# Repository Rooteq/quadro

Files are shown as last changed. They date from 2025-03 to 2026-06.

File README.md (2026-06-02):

# Quadro
Quadro is the name of my ros2 quadruped project.

## Overview
I'm developing 12 DoF quadruped robot as a part of my master theses as well as my hobby.
The project consists of:
- 3D printed physical physical - fully designed by me. The motors are Steadywin gim6010-8 connected to Raspberry Pi 5 with the use of CAN bus. In the future Nvidia Jetson Orin Nano will be added as a secondary computer for visual SLAM.
- Simulated robot in Isaac Lab.

Right now, only the naive position controller works - robot is able to walk, but only in crawl (one leg up at one time). Model-based predictive controller is in the works.
Controllers, hardware interface and internal communication are based on ROS2 Jazzy libraries. It requires custom **ros_odrive** library with **ros2_control** hardware interface modified to work in my configuration: 
[custom ros_odrive](https://github.com/Rooteq/ros_odrive). That's how the robot looks:
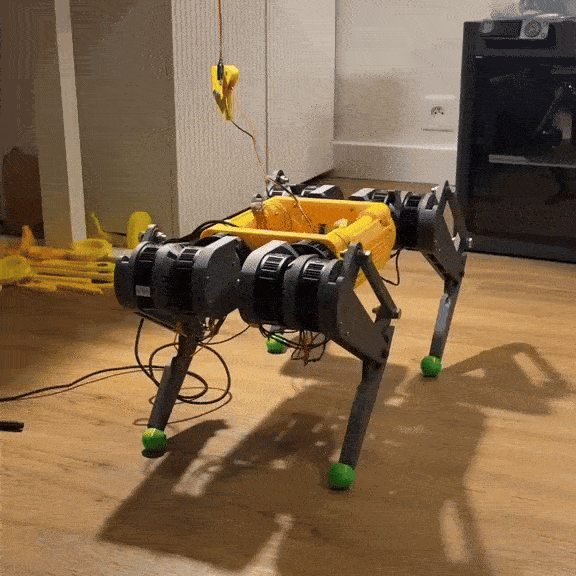
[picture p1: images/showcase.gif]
real robot moving


Implementation of the convex model predictive control using this platform is in this repo: [quadruped_mpc_control](https://github.com/Rooteq/quadruped_control/tree/mpc_tests)

## THIS PROJECT IS IN ACTIVE DEVELOPMENT

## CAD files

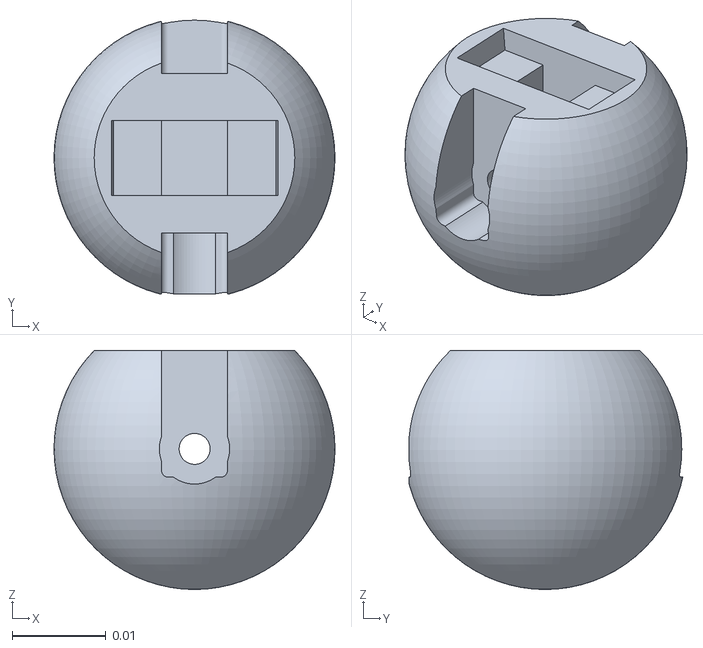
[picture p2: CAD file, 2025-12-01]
description/assets/feet.stl
0.03 x 0.0292 x 0.0255

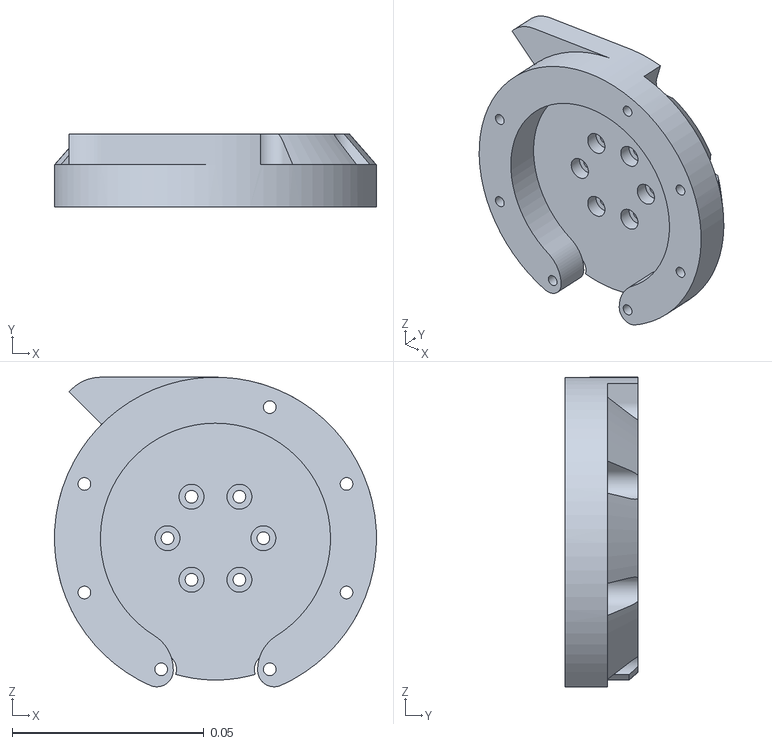
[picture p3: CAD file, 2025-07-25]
description/leg_assets/lin_2_bl.stl
0.084 x 0.019 x 0.0808

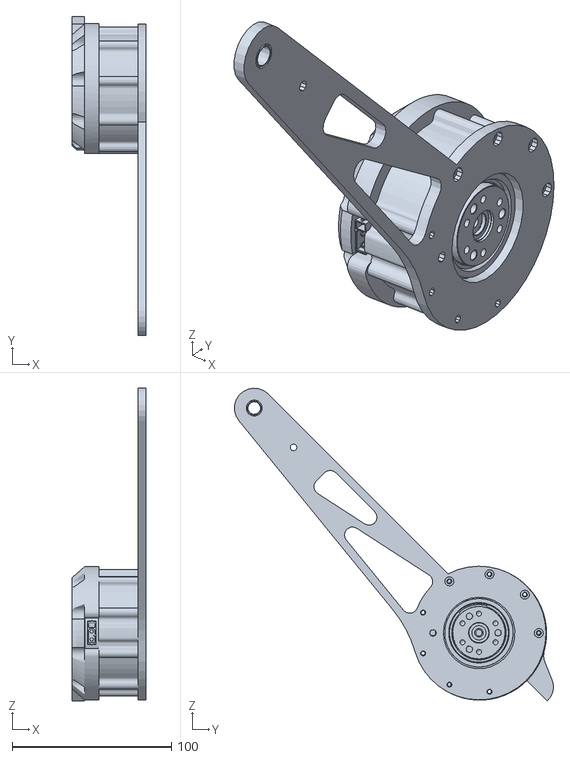
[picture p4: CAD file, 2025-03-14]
description/meshes/link_2_1.stl
46.5 x 200.6 x 196.5

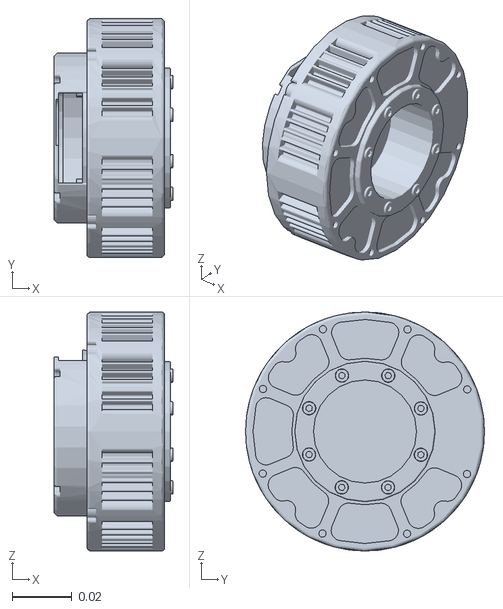
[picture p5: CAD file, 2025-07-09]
description/motor_assets/motor.stl
0.0398 x 0.08 x 0.08

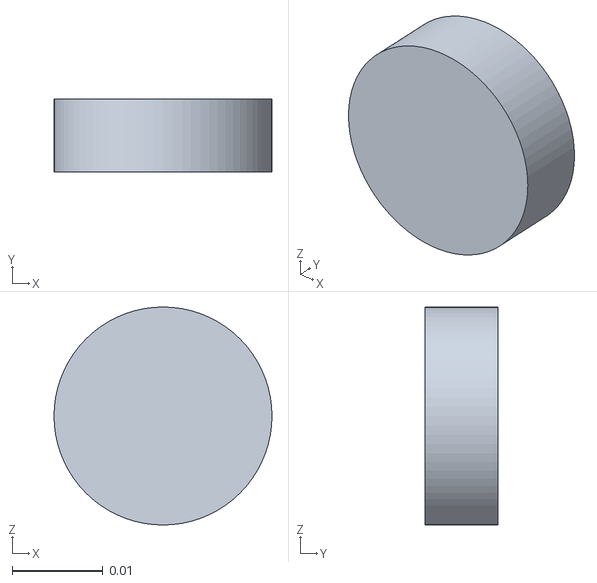
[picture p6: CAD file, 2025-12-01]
description/assets/bearing.stl
0.024 x 0.008 x 0.024

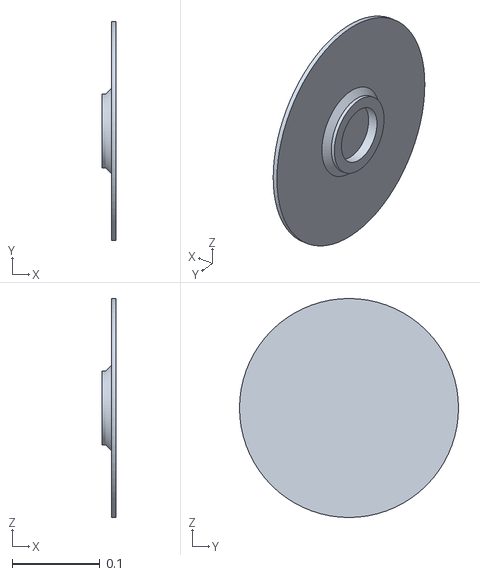
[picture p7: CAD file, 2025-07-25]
description/leg_assets/stand.stl
0.016 x 0.25 x 0.25

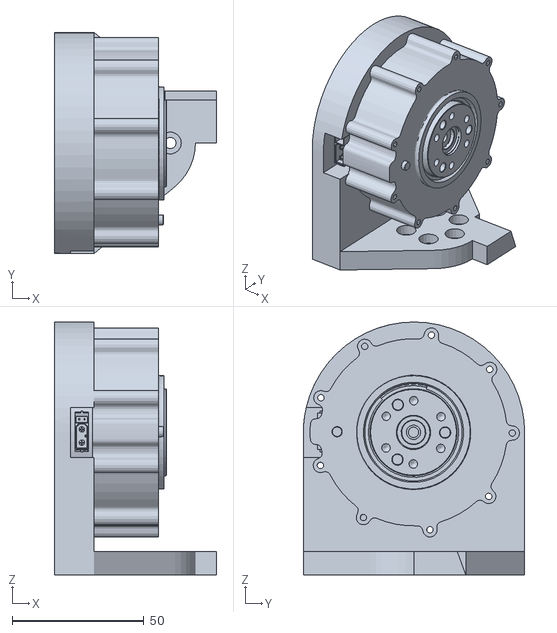
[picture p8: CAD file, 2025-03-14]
description/meshes/link_1_1.stl
61.5 x 84.0 x 96.0

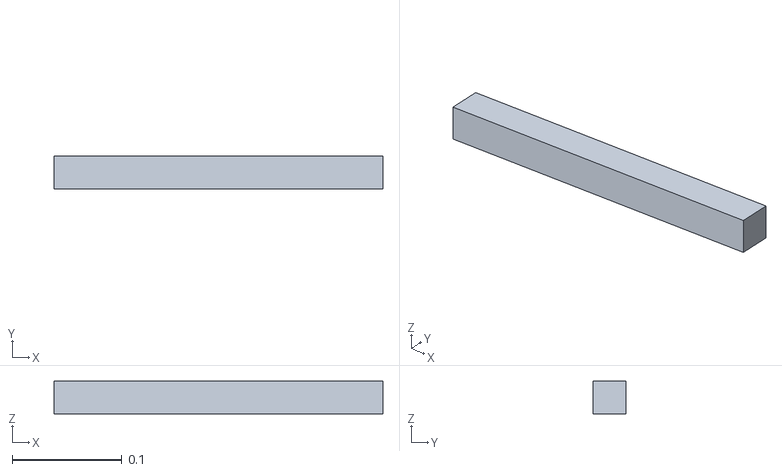
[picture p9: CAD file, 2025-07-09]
description/motor_assets/link.stl
0.3 x 0.03 x 0.03

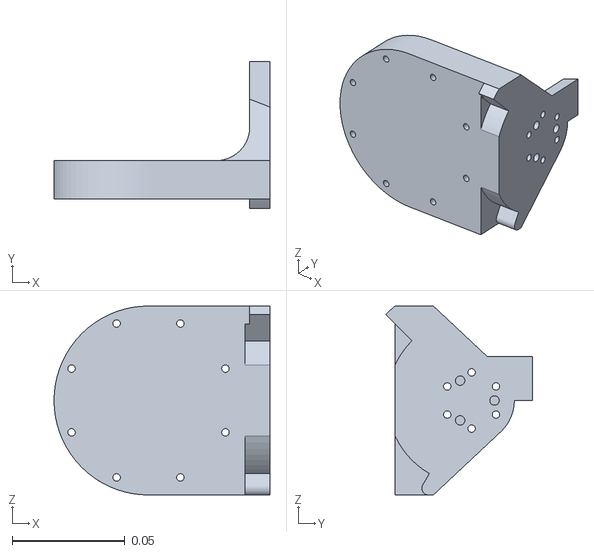
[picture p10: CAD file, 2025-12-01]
description/assets/lin_1_support_bl.stl
0.096 x 0.0652 x 0.084

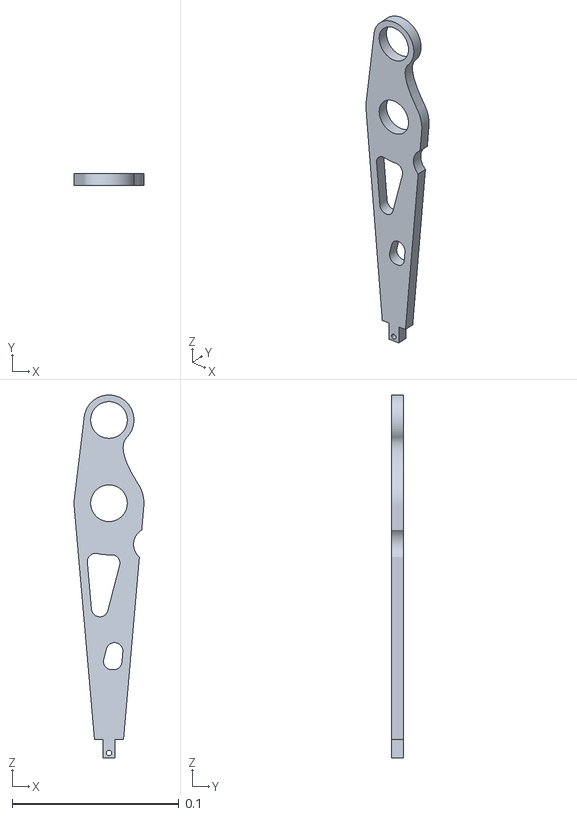
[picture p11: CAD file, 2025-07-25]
description/leg_assets/lin_4_l.stl
0.042 x 0.007 x 0.218

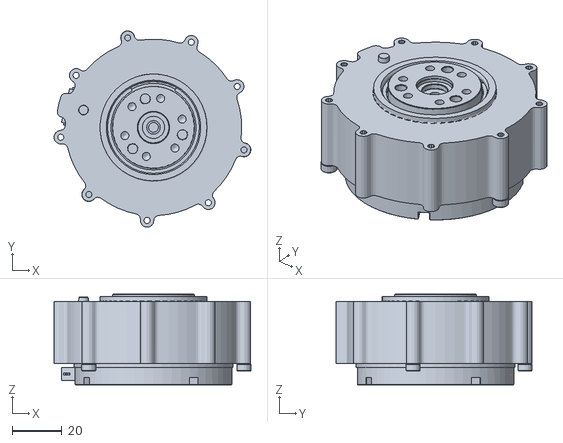
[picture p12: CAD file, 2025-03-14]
description/meshes/base_link.stl
79.3 x 79.0 x 36.5

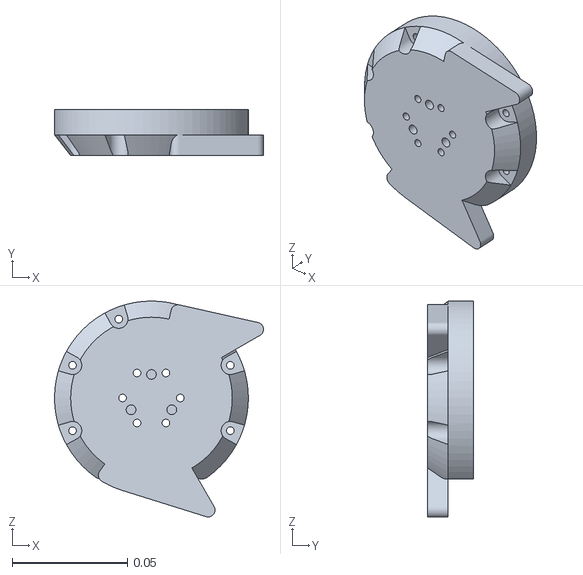
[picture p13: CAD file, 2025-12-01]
description/assets/lin_2_fr.stl
0.0905 x 0.02 x 0.0935

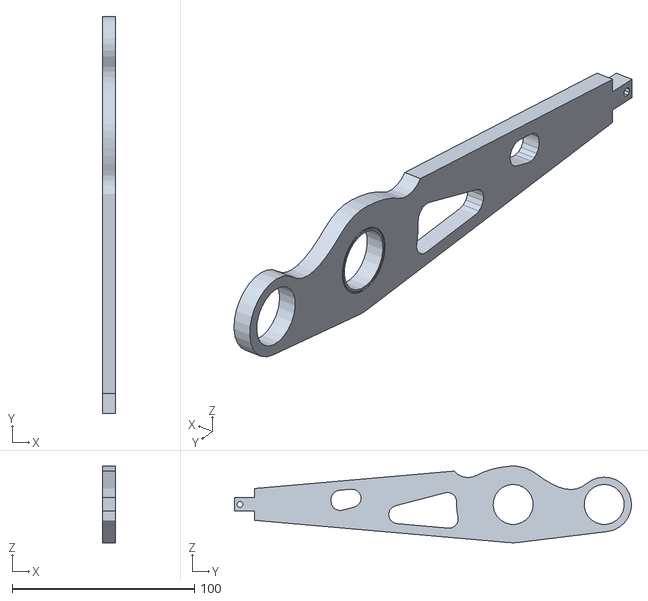
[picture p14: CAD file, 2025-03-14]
description/meshes/link_3_1.stl
7.00 x 218.0 x 42.1

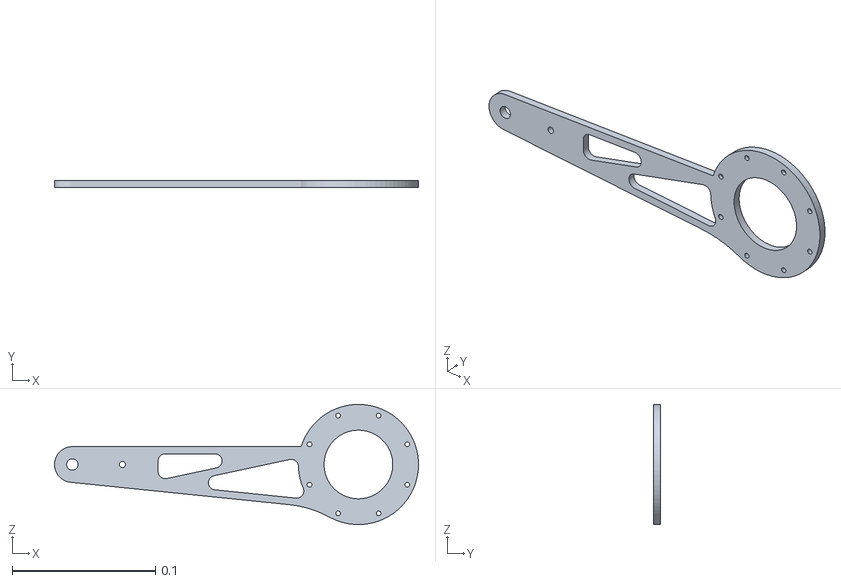
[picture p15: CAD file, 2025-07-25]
description/leg_assets/lin_3_bot_l.stl
0.254 x 0.005 x 0.084

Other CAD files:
description/leg_assets/lin_4_r.stl
description/assets/lin_1_support_fr.stl
description/meshes/cybergear_body.stl
description/assets/mid_clamp.stl
description/assets/back_plate.stl
description/assets/back_stop.stl
description/assets/battery.stl
description/assets/bot_4.stl
description/assets/bot_l.stl
description/assets/bot_pipe_half.stl
description/assets/l4_l.stl
description/assets/l4_r.stl
description/assets/lin_1_support_br.stl
description/assets/lin_1_support_fl.stl
description/assets/lin_2_bl.stl
description/assets/lin_2_br.stl
description/assets/lin_2_fl.stl
description/assets/mid_l.stl
description/assets/mid_r.stl
description/assets/pierdolnik.stl
description/assets/r_pi.stl
description/assets/side_cover.stl
description/assets/side_pipe.stl
description/assets/top_l.stl
description/assets/top_r.stl
description/leg_assets/back_plate.stl
description/leg_assets/back_stop.stl
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

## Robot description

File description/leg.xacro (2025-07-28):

<?xml version="1.0" ?>
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
<robot name="robot" xmlns:xacro="http://www.ros.org/wiki/xacro">
<xacro:arg name="sim_mode" default="false"/>

<xacro:if value="$(arg sim_mode)">
  <xacro:include filename="$(find quadro)/description/leg.gazebo" />
</xacro:if>

<xacro:unless value="$(arg sim_mode)">
  <xacro:include filename="$(find quadro)/description/robot_ros2_control.xacro" />
</xacro:unless>
  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
  <link name="world"/>

  <joint name="fixed" type="fixed">
    <parent link="world"/>
    <child link="motor"/>
  </joint>

  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
  <link name="motor">
    <inertial>
      <origin xyz="0.000167595 0.0335997 0.0536899" rpy="0 0 0"/>
      <mass value="0.840992"/>
      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
    </inertial>
    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
  </link>
  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
  <link name="shaft">
    <inertial>
      <origin xyz="-0.00365203 -0.00743033 -0.0538481" rpy="0 0 0"/>
      <mass value="0.500834"/>
      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
    </inertial>
    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
  </link>
  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
  <link name="lin_2_br">
    <inertial>
      <origin xyz="-0.00583084 -0.0129347 -0.0439786" rpy="0 0 0"/>
      <mass value="0.55866"/>
      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
    </inertial>
    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
  </link>
  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
  <link name="lin_top_r">
    <inertial>
      <origin xyz="0.000209323 -0.00444903 -0.0125923" rpy="0 0 0"/>
      <mass value="0.140118"/>
      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
    </inertial>
    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
  </link>
  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
  <joint name="joint_br_3" type="revolute">
    <origin xyz="8.25728e-16 -8.32667e-17 -0.0485" rpy="-1.90199e-14 -3.69158e-14 0.436332"/>
    <parent link="lin_2_br"/>
    <child link="lin_top_r"/>
    <axis xyz="0 0 -1"/>
    <limit effort="10" velocity="10" lower="-3.141592653589793" upper="3.141592653589793"/>
  </joint>
  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
  <link name="lin_4_r">
    <inertial>
      <origin xyz="-0.00037679 -0.0270176 -5.21118e-10" rpy="0 0 0"/>
      <mass value="0.0488058"/>
      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
    </inertial>
    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
  </link>
  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
  <joint name="br_l4_l3" type="revolute">
    <origin xyz="-0.068404 -0.187939 -0.074" rpy="3.14159 -3.7582e-14 0.436332"/>
    <parent link="lin_2_br"/>
    <child link="lin_4_r"/>
    <axis xyz="0 0 -1"/>
    <limit effort="10" velocity="10" lower="-3.141592653589793" upper="3.141592653589793"/>
    <mimic joint="joint_br_3" multiplier="-1.0"/>
  </joint>
  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
  <joint name="joint_br_2" type="revolute">
    <origin xyz="-0.0035 -0.00606218 -0.0735" rpy="1.5708 8.1119e-15 -0.523599"/>
    <parent link="shaft"/>
    <child link="lin_2_br"/>
    <axis xyz="0 0 -1"/>
    <limit effort="10" velocity="10" lower="-3.141592653589793" upper="3.141592653589793"/>
  </joint>
  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
  <joint name="joint_br_1" type="revolute">
    <origin xyz="-0.055 0.0342754 0.061" rpy="-3.14159 -2.04333e-29 -1.5708"/>
    <parent link="motor"/>
    <child link="shaft"/>
    <axis xyz="0 0 -1"/>
    <limit effort="10" velocity="10" lower="-3.141592653589793" upper="3.141592653589793"/>
  </joint>
  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
  <link name="shaft_2">
    <inertial>
      <origin xyz="-0.00365203 0.00743033 -0.0535667" rpy="0 0 0"/>
      <mass value="0.500834"/>
      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
    </inertial>
    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
  </link>
  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
  <link name="motor_2">
    <inertial>
      <origin xyz="-0.00512367 0.0104232 -0.0435875" rpy="0 0 0"/>
      <mass value="0.551476"/>
      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
    </inertial>
    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
  </link>
  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
  <link name="shaft_3">
    <inertial>
      <origin xyz="0.00329395 0.00299792 -0.0125923" rpy="0 0 0"/>
      <mass value="0.140118"/>
      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
    </inertial>
    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
  </link>
  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
  <joint name="joint_bl_3" type="revolute">
    <origin xyz="9.22873e-16 8.32667e-17 -0.0485" rpy="8.67076e-16 -1.64245e-15 0.349066"/>
    <parent link="motor_2"/>
    <child link="shaft_3"/>
    <axis xyz="0 0 1"/>
    <limit effort="10" velocity="10" lower="-3.141592653589793" upper="3.141592653589793"/>
  </joint>
  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
  <link name="lin_4_l">
    <inertial>
      <origin xyz="-0.000328446 -0.0235508 -0.0035" rpy="0 0 0"/>
      <mass value="0.0559903"/>
      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
    </inertial>
    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
  </link>
  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
  <joint name="bl_l4_l3" type="revolute">
    <origin xyz="-0.068404 0.187939 -0.0705" rpy="7.63706e-16 -1.37363e-15 -0.436332"/>
    <parent link="motor_2"/>
    <child link="lin_4_l"/>
    <axis xyz="0 0 1"/>
    <limit effort="10" velocity="10" lower="-3.141592653589793" upper="3.141592653589793"/>
    <mimic joint="joint_bl_3" multiplier="1.0"/>
  </joint>
  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
  <joint name="joint_bl_2" type="revolute">
    <origin xyz="-0.0035 0.00606218 -0.0735" rpy="-1.5708 3.45644e-16 0.523599"/>
    <parent link="shaft_2"/>
    <child link="motor_2"/>
    <axis xyz="0 0 1"/>
    <limit effort="10" velocity="10" lower="-3.141592653589793" upper="3.141592653589793"/>
  </joint>
  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
  <joint name="joint_bl_1" type="revolute">
    <origin xyz="0.055 0.0342754 0.061" rpy="-3.14159 2.64698e-23 -1.5708"/>
    <parent link="motor"/>
    <child link="shaft_2"/>
    <axis xyz="0 0 -1"/>
    <limit effort="10" velocity="10" lower="-3.141592653589793" upper="3.141592653589793"/>
  </joint>
</robot>

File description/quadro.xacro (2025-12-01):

<?xml version="1.0" ?>
<robot name="quadro" xmlns:xacro="http://www.ros.org/wiki/xacro">
<xacro:arg name="sim_mode" default="false"/>

<xacro:include filename="$(find quadro)/description/materials.xacro" />
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
<xacro:if value="$(arg sim_mode)">
  <xacro:include filename="$(find quadro)/description/robot.gazebo" />
</xacro:if>

<xacro:unless value="$(arg sim_mode)">
  <xacro:include filename="$(find quadro)/description/ros2_control.xacro" />
</xacro:unless>

  <link name="back_plate">
    <inertial>
      <origin xyz="-0.139034 0.0124348 -0.00910543" rpy="0 0 0"/>
      <mass value="1.72721"/>
      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
    </inertial>
    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
  </link>
  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
  <link name="shaft">
    <inertial>
      <origin xyz="-0.00615624 0.00516896 -0.0539841" rpy="0 0 0"/>
      <mass value="0.498148"/>
      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
    </inertial>
    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
  </link>
  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
  <link name="shaft_2">
    <inertial>
      <origin xyz="0.0151537 -0.00339527 -0.0487431" rpy="0 0 0"/>
      <mass value="0.644469"/>
      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
    </inertial>
    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
  </link>
  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
  <link name="shaft_3">
    <inertial>
      <origin xyz="0.00467702 0.00467702 -0.014107" rpy="0 0 0"/>
      <mass value="0.152155"/>
      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
    </inertial>
    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
  </link>
  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
  <joint name="br_m3_s3" type="revolute">
    <origin xyz="-1.13798e-15 1.27676e-15 -0.0495" rpy="-2.27596e-15 -6.93889e-17 -0.226893"/>
    <parent link="shaft_2"/>
    <child link="shaft_3"/>
    <axis xyz="0 0 1"/>
    <limit effort="10" velocity="12" lower="-3.14" upper="3.14"/>
    <joint_properties friction="0.5"/>
    <mimic joint="br_l4_l3" multiplier="1.0"/>
  </joint>
  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
  <link name="l4_r">
    <inertial>
      <origin xyz="0.00132696 -0.0488871 -0.00598393" rpy="0 0 0"/>
      <mass value="0.128547"/>
      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
    </inertial>
    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
  </link>
  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
  <joint name="br_l4_l3" type="revolute">
    <origin xyz="0.159217 -0.0159373 -0.0735" rpy="-2.22045e-15 2.60902e-15 -1.01229"/>
    <parent link="shaft_2"/>
    <child link="l4_r"/>
    <axis xyz="0 0 1"/>
    <limit effort="10" velocity="12" lower="-3.14" upper="3.14"/>
    <joint_properties friction="0.5"/>
  </joint>
  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
  <joint name="br_m2_s2" type="revolute">
    <origin xyz="-0.00494975 0.00494975 -0.0735" rpy="-2.35619 1.5708 0"/>
    <parent link="shaft"/>
    <child link="shaft_2"/>
    <axis xyz="0 0 1"/>
    <limit effort="10" velocity="12" lower="-3.14" upper="3.14"/>
    <joint_properties friction="0.5"/>
  </joint>
  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
  <joint name="br_m1_s1" type="revolute">
    <origin xyz="-0.194034 0.126935 -0.00844105" rpy="-1.5708 -8.11125e-15 3.14159"/>
    <parent link="back_plate"/>
    <child link="shaft"/>
    <axis xyz="0 0 1"/>
    <limit effort="10" velocity="12" lower="-3.14" upper="3.14"/>
    <joint_properties friction="0.5"/>
  </joint>
  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
  <link name="shaft_4">
    <inertial>
      <origin xyz="0.00614962 0.00518173 -0.0536475" rpy="0 0 0"/>
      <mass value="0.498298"/>
      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
    </inertial>
    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
  </link>
  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
  <link name="shaft_5">
    <inertial>
      <origin xyz="0.0112104 0.0105552 -0.0487431" rpy="0 0 0"/>
      <mass value="0.644469"/>
      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
    </inertial>
    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
  </link>
  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
  <link name="shaft_6">
    <inertial>
      <origin xyz="-0.00467702 0.00467702 -0.014107" rpy="0 0 0"/>
      <mass value="0.152155"/>
      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
    </inertial>
    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
  </link>
  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
  <joint name="bl_m3_s3" type="revolute">
    <origin xyz="7.21645e-16 -1.52656e-16 -0.0495" rpy="1.21014e-14 5.23193e-15 -2.3911"/>
    <parent link="shaft_5"/>
    <child link="shaft_6"/>
    <axis xyz="0 0 1"/>
    <limit effort="10" velocity="12" lower="-3.14" upper="3.14"/>
    <joint_properties friction="0.5"/>
    <mimic joint="bl_l4_l3" multiplier="1.0"/>
  </joint>
  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
  <link name="l4_l">
    <inertial>
      <origin xyz="0.00132707 0.0488871 -0.00598393" rpy="0 0 0"/>
      <mass value="0.128547"/>
      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
    </inertial>
    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
  </link>
  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
  <joint name="bl_l4_l3" type="revolute">
    <origin xyz="0.129917 0.0934105 -0.0735" rpy="-1.63758e-14 6.77236e-15 1.53589"/>
    <parent link="shaft_5"/>
    <child link="l4_l"/>
    <axis xyz="0 0 1"/>
    <limit effort="10" velocity="12" lower="-3.14" upper="3.14"/>
    <joint_properties friction="0.5"/>
  </joint>
  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
  <joint name="bl_m2_s2" type="revolute">
    <origin xyz="0.00494975 0.00494975 -0.0735" rpy="-1.5708 1.0472 -0.785398"/>
    <parent link="shaft_4"/>
    <child link="shaft_5"/>
    <axis xyz="0 0 1"/>
    <limit effort="10" velocity="12" lower="-3.14" upper="3.14"/>
    <joint_properties friction="0.5"/>
  </joint>
  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
  <joint name="bl_m1_s1" type="revolute">
    <origin xyz="-0.0840337 0.126935 -0.00844105" rpy="-1.5708 -9.60008e-14 -3.14159"/>
    <parent link="back_plate"/>
    <child link="shaft_4"/>
    <axis xyz="0 0 1"/>
    <limit effort="10" velocity="12" lower="-3.14" upper="3.14"/>
    <joint_properties friction="0.5"/>
  </joint>
  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
  <link name="shaft_7">
    <inertial>
      <origin xyz="-0.00608141 -0.00524995 -0.0536475" rpy="0 0 0"/>
      <mass value="0.498298"/>
      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
    </inertial>
    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
  </link>
  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
  <link name="shaft_8">
    <inertial>
      <origin xyz="0.0156244 -0.00329073 -0.0486585" rpy="0 0 0"/>
      <mass value="0.64666"/>
      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
    </inertial>
    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
  </link>
  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
  <link name="shaft_9">
    <inertial>
      <origin xyz="0.00467702 0.00467702 -0.014107" rpy="0 0 0"/>
      <mass value="0.152155"/>
      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
    </inertial>
    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
  </link>
  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
  <joint name="fr_m3_s3" type="revolute">
    <origin xyz="0 -2.77556e-17 -0.0495" rpy="-1.11022e-15 -1.11022e-15 -0.226893"/>
    <parent link="shaft_8"/>
    <child link="shaft_9"/>
    <axis xyz="0 0 1"/>
    <limit effort="10" velocity="12" lower="-3.14" upper="3.14"/>
    <joint_properties friction="0.5"/>
    <mimic joint="fr_l4_l3" multiplier="1.0"/>
  </joint>
  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
  <link name="l4_r_2">
    <inertial>
      <origin xyz="0.00132696 -0.0488871 -0.00598393" rpy="0 0 0"/>
      <mass value="0.128547"/>
      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
    </inertial>
    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
  </link>
  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
  <joint name="fr_l4_l3" type="revolute">
    <origin xyz="0.159217 -0.0159373 -0.0735" rpy="1.38778e-15 -2.77556e-16 -1.01229"/>
    <parent link="shaft_8"/>
    <child link="l4_r_2"/>
    <axis xyz="0 0 1"/>
    <limit effort="10" velocity="12" lower="-3.14" upper="3.14"/>
    <joint_properties friction="0.5"/>
  </joint>
  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
  <joint name="fr_m2_s2" type="revolute">
    <origin xyz="-0.00494975 -0.00494975 -0.0735" rpy="0.785398 -1.5708 0"/>
    <parent link="shaft_7"/>
    <child link="shaft_8"/>
    <axis xyz="0 0 1"/>
    <limit effort="10" velocity="12" lower="-3.14" upper="3.14"/>
    <joint_properties friction="0.5"/>
  </joint>
  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
  <joint name="fr_m1_s1" type="revolute">
    <origin xyz="-0.194034 -0.102065 -0.00844105" rpy="1.5708 -0 -3.14159"/>
    <parent link="back_plate"/>
    <child link="shaft_7"/>
    <axis xyz="0 0 1"/>
    <limit effort="10" velocity="12" lower="-3.14" upper="3.14"/>
    <joint_properties friction="0.5"/>
  </joint>
  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
  <link name="motor">
    <inertial>
      <origin xyz="0.00608801 -0.00523719 -0.0539842" rpy="0 0 0"/>
      <mass value="0.498148"/>
      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
    </inertial>
    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
  </link>
  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
  <link name="motor_2">
    <inertial>
      <origin xyz="-0.0154574 -0.00343083 -0.0486585" rpy="0 0 0"/>
      <mass value="0.64666"/>
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

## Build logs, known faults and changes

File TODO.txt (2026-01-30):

TODO:
WHEN WALK GAIT (CRAWL) - let the body shift in y axis instead of rotate! - it's way more stable

Walking controller redesign and refactor - it should be possible to have walking on a plane and yaw happen at the same time,
also the controller should take in walking speed (in m/s) and generate corresponding gait patterns

Hardware: 
- make space for USB cable in each link,
- change link 1 design so that it can rotate clockwise more (For BR)
- Make space for a stop in link 4 !
- in link 3 top, make the stopper longer (?)

Each motor setup:
- calibrate and save,
- decrease current to 10A max,
- decrease max vel to 420 rpm,
- enable can / disable can resistor on some,
- change filter bandwidth to 25

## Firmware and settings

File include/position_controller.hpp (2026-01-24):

#pragma once
#include "inverse_kinematics.hpp"
#include "array"

#define TRAJECTORY_POINTS 24
#define DOWN_PHASES 6 //number of times an individual leg touches the ground during the whole phase

namespace IK
{

using vec3 = Eigen::Vector3d;

// Again starting from FL
typedef Eigen::Matrix<unsigned int, 4, 4> CrawlMatrix;
typedef Eigen::Matrix<unsigned int, 4, 2> WalkMatrix;

struct LegTrajectory
{
    std::vector<vec3> up{};

    vec3 leg_down_offset{0.0,0.0,0.0};

    vec3 current_leg_pos;
    bool up_movement = false;
    int i = 0;
    int k = 0;

    double step_base, step_height;
    double rotation_angle_{0.0};

    unsigned int trajectory_points = 0;
    unsigned int down_phases = 0;
    void set_trajectory_points(const unsigned int trajectory_points, const unsigned int down_phases)
    {
        up.resize(trajectory_points);
        this->trajectory_points = trajectory_points;
        this->down_phases = down_phases;
    }

    void calculate_shape(const double base, const double height, const double walking_speed) // add params here
    {
        step_base = base;
        step_height = height;

        const double x_step = walking_speed * step_base/(trajectory_points/2);

        double coeff = height / (base/2);

        // SET POINT, WHERE THE LEG WILL RAISE FROM
        up[0] << walking_speed*(-step_base/2), 0.0, 0.0;

        for(int i = 1; i < trajectory_points; ++i)
        {
            if(i < trajectory_points/2)
                up[i] << (up[i-1].x() + x_step/2) , 0.0 , (up[i-1].z() + coeff * x_step/2);
            else
                up[i] << (up[i-1].x() + x_step/2) , 0.0 , (up[i-1].z() - coeff * x_step/2);
        }

        const double x_step_down = walking_speed * step_base/(trajectory_points*down_phases); 
        leg_down_offset = {x_step_down, 0.0, 0.0};

        // Apply rotation if needed
        apply_rotation();
    }

    void set_rotation(double rotation_angle)
    {
        rotation_angle_ = rotation_angle;
        // apply_rotation();
    }

    void apply_rotation()
    {
        if (rotation_angle_ != 0.0) {
            Eigen::Matrix3d rotation;
            rotation = Eigen::AngleAxisd(rotation_angle_, Eigen::Vector3d::UnitZ());
            
            for(auto& point : up) {
                point = rotation * point;
            }

            leg_down_offset = rotation * leg_down_offset;
        }
    }

    const vec3& get_next_up_pos()
    {
        int j = i;
        i++;

        if(i == trajectory_points)
        {
            i = 0;
            up_movement = false;
        }

        current_leg_pos = up[j];
        return current_leg_pos;
    }

    const vec3& get_next_down_step() // can add PID controler here?
    {
        current_leg_pos -= leg_down_offset;

        return current_leg_pos;
    }
};

class GaitController
{

public:

    virtual ~GaitController() = default;
    virtual void apply_gait() = 0;


    void apply_control()
    {
        // apply_rotation();
        apply_gait();
        apply_rotation();
        calculate_joint_positions();
    }
    
    void startup()
    {
        for(Leg leg : legIterator())
        {
            legs_ik.calcJointPositions(leg, default_leg_pos.x(), default_leg_pos.y(), default_leg_pos.z());
            legs_pos[leg] = default_leg_pos;
        }
    }

    void set_leg_xyz_position(Leg leg, double x, double y, double z)
    {
        legs_ik.calcJointPositions(leg, x, y, z);
        legs_pos[leg] << x,y,z;
    }

    const LegJointPositions& get_leg_joint_positions(Leg leg)
    {
        return legs_ik.legs[leg];
    }

    void set_rotation(const double roll, const double pitch, const double yaw)
    {
        robot_rot.x() = roll;
        robot_rot.y() = pitch;
        robot_rot.z() = yaw;
    }

    void set_walking_parameters(const double walk_speed, const double yaw_speed, 
                               const double walking_rotation, const bool walking_enabled)
    {
        walking_speed_ = walk_speed;
        walking_yaw_speed_ = yaw_speed;
        walking_rotation_angle_ = walking_rotation;
        walking_enabled_ = walking_enabled;
        
        // This is very much temporary, robot rotation should be calculated based on a rectangle inscribed in a circle (first thought)
        // It should be possible to have walking on a plane and yaw happen at the same time!!! - needs controller redesign
        if (walking_enabled_) {
            for(Leg leg : legIterator()) {
                if(yaw_speed != 0)
                {
                    if(yaw_speed > 0)
                    {
                        if(leg == Leg::FL || leg == Leg::FR)
                        {
                            legs_trajectory[leg].set_rotation(M_PI/2);
                        }
                        else
                        {
                            legs_trajectory[leg].set_rotation(-M_PI/2);
                        }
                    }
                    else
                    {
                        if(leg == Leg::BL || leg == Leg::BR)
                        {
                            legs_trajectory[leg].set_rotation(M_PI/2);
                        }
                        else
                        {
                            legs_trajectory[leg].set_rotation(-M_PI/2);
                        }

                    }

                    walking_speed_ = std::abs(yaw_speed); // This shit is so bad
                }
                else 
                    legs_trajectory[leg].set_rotation(walking_rotation_angle_);
            }
        }
    }
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

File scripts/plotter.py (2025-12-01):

import odrive
# from odrive.plotting import start_liveplotter
from odrive.utils import start_liveplotter
import matplotlib as plt

print(odrive.__version__)

odrv0 = odrive.find_any()


class ShiftedProperty:
    def __init__(self, prop, offset):
        self.prop = prop
        self.offset = offset
    
    def __call__(self):
        return [self.prop()[0] + self.offset]

offset = odrv0.axis0.encoder.config.index_offset

properties_to_plot = [
    odrv0.axis0.encoder._pos_estimate_property,
    odrv0.axis0.encoder._vel_estimate_property
]

print("starting liveplotter...")
# Pass the list of properties to the start_liveplotter function
start_liveplotter(properties_to_plot)

# offset = 10.0  # your desired offset
# start_liveplotter([
#     odrv0.axis0.encoder._pos_estimate_property,
#     ShiftedProperty(odrv0.axis0.controller._pos_setpoint_property, offset)
# ], '1')

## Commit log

2025-02-20 preparation for hardware interface
    [controllers.yaml, cybergear_body.stl, cybergear_servo.urdf.xacro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]
2025-02-20 hw_int state: simulated motor rotation
    [controllers.yaml, cybergear_servo.urdf.xacro, cybergear_servo.xacro]
2025-02-20 enable and disable motor on activate and deactivate
2025-02-21 reading pos and vel from motor
2025-02-26 basic multi motor support added
    [cybergear_servo.xacro]
2025-02-28 dual motor works
    [controllers.yaml, cybergear_servo.urdf.xacro, cybergear_servo.xacro]
2025-02-28 added auto zeroing
    [cybergear_servo.xacro]
2025-02-28 streamlined creating messages
    [cybergear_servo.xacro]
2025-03-01 changed default can frame type to can_msgs
2025-03-14 added basic gazebo simulation
    [base_link.stl, controllers.yaml, cybergear_body.stl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]
2025-03-15 fixed arm to ground
    [quadro.xacro]
2025-03-21 2 dof mode workd
    [quadro.xacro, ros2_control.xacro]
2025-03-21 3 dof inverse kinematics (sorta) work
2025-04-15 funcional 3dof inverse kinematics
2025-07-09 added steadywin motor simulation with basic pinocchio integration
    [link.stl, motor.stl, robot.xacro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]
2025-07-10 basic computed torque controller works for 1 motor xd
2025-07-10 got 3dof robot to work
    [bearing.stl, lin_1_support_br.stl, lin_2_br.stl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]
2025-07-25 added full robot model
    [back_plate.stl, back_stop.stl, battery.stl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]
2025-07-27 added backplate to the simulation leg
    [back_plate.stl, back_stop.stl, bearing.stl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]
2025-07-28 added second leg
    [leg.xacro, leg_controllers.yaml, lin_1_support_bl.stl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]
2025-07-30 inverse kinematics of 4 legs now work
    [robot.xacro]
2025-08-02 added simple body rotation (yaw still not perfect)
2025-08-02 there is still a problem with yaw
2025-08-03 onto something with back legs
    [leg_rotated.xacro]
2025-08-03 back legs inverse kinematics with joint 1 offset now done
    [leg.xacro, leg_non_rotated.xacro]
2025-08-04 separated basic inverse kinematics calculations
2025-08-04 changed controller to pure position
    [joint_position_controllers.yaml]
2025-08-04 added simple joint velocity limiter
2025-08-05 added rotation when walking
    [robot.xacro]
2025-08-06 changed model for longer legs, basic crawl now basically works, still unstable
    [feet.stl, joint_position_controllers.yaml, lin_4_l.stl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]
2025-08-06 added own world (still default empty)
    [world.sdf]
2025-08-17 added files necessary for isaac sim setup
    [joint_position_controllers.yaml, robot.xacro, robot_full_urdf.urdf]
2025-08-17 added simple and VERY rough robot yaw
2025-09-05 motors are now rotating in one direction - cant reverse real motors
    [robot.xacro]
2025-09-05 started integration with hardware
    [controllers.yaml, one_motor_control.xacro, one_motor_params.yaml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]
2025-09-06 first hardware integration tests
    [quadro.xacro]
2025-09-06 isolated BR leg
    [controllers.yaml, ros2_control.xacro]
2025-09-06 Hardware BR leg is now working
    [controllers.yaml, ros2_control.xacro]
2025-09-30 BL and BR legs working
    [controllers.yaml, ros2_control.xacro]
2025-10-12 added missing joint controllers
    [controllers.yaml, ros2_control.xacro]
2025-10-12 fixed type
    [ros2_control.xacro]
2025-10-12 added mising motors
2025-10-15 fixed isaac sim model
    [robot_full_urdf.urdf]
2025-12-01 changed control xacro file
    [ros2_control.xacro]
2025-12-01 added scripts for tuning motors
2025-12-01 added v2 simulation design
    [back_plate.stl, back_stop.stl, bearing.stl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]
